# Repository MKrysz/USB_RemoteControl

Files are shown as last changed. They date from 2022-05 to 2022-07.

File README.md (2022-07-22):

# USB Remote Control

## About

The goal of this project was to make an USB dongle allowing you to remotely control your PC with your phone with minimal setup. I achieved it by combining microcontroller with USB HID interface and Bluetooth module. Thanks to utilizing standard HID interface the receiver side is plug-and-play. Only setup is needed on smartphones side, i.e. installing the app and connecting to the dongle.

## Hardware

Schematic

Schematic was made in KiCad

I used STM32F103C6 MCU as it was the cheapest MCU with USB that I had. For Bluettoth connection I used JDY-33 Bluetooth module that can be easily controlled via UART interface. I also added some LEDs and buttons for showing information like state of connection.

The boards were manufactured by JLCPCB

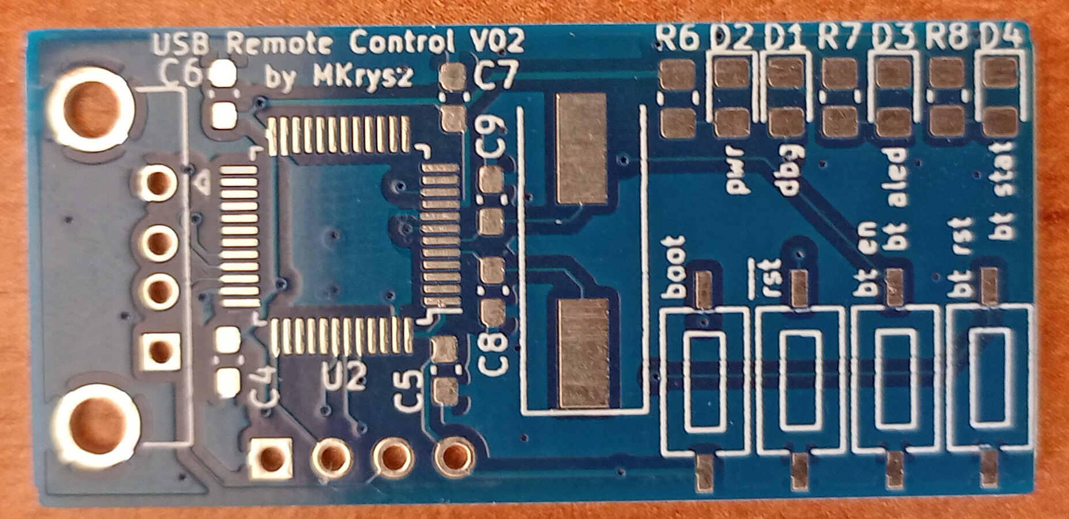
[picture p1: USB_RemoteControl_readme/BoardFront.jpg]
BoardFront

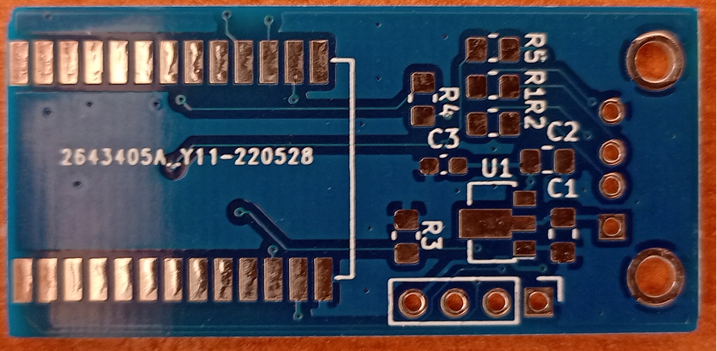
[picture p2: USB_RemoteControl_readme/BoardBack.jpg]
BoardBack


After soldering everything and trying to test the board I found out I could get it to connect to PC via USB. After some research I found out that my MCU is one of few from STM32 family that does not embed pullup resistor on D+ line, so I had to add it. Fully assembled device is shown below:

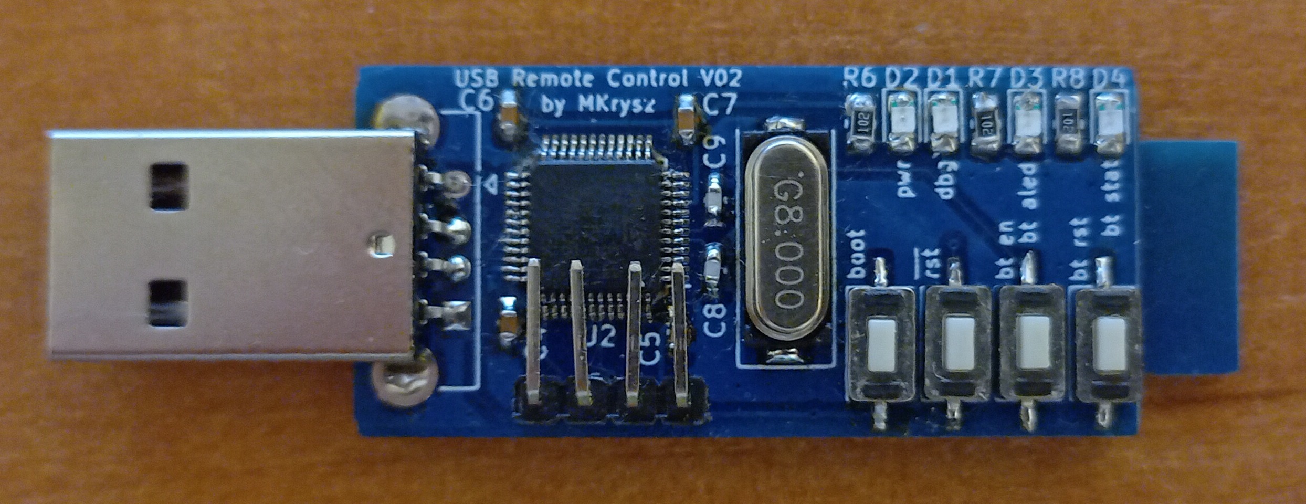
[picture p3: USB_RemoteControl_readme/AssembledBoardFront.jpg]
BoardFront

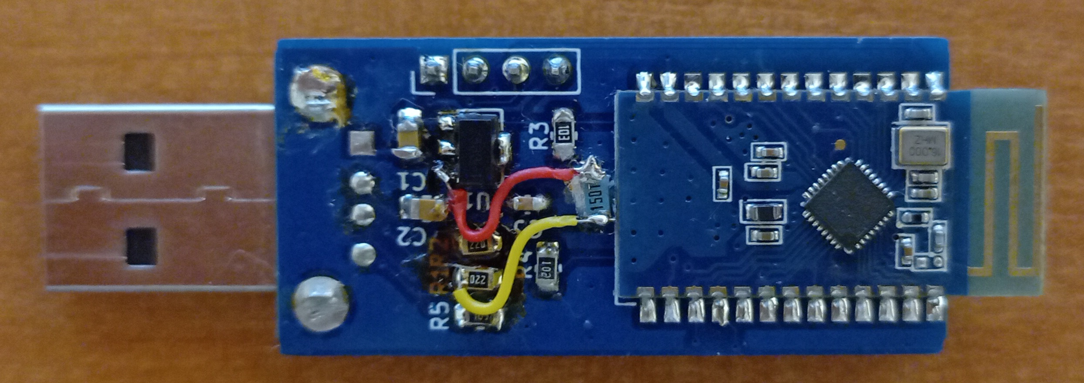
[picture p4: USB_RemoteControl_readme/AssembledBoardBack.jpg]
BoardBack


<!-- ## Embedded Software

Embedded software was made using [STM32CubeMX](https://www.st.com/en/development-tools/stm32cubemx.html) and VSCode using [stm32-for-vscode](https://github.com/bmd-studio/stm32-for-vscode) extension.

F
**Think about what to write here (maybe smth about USB descriptor?)** -->

## Android App

Android App was made using [MIT App Inventor](https://appinventor.mit.edu/), and in design it tries to imitate classical remote control with some additional functions like send text or change current tab in a browser. Current version heavily supports controlling YTMusic web player.

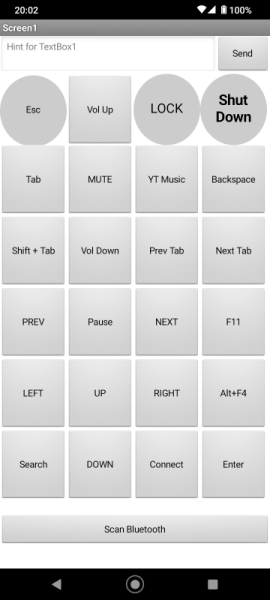
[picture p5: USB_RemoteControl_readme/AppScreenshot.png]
App Screenshot


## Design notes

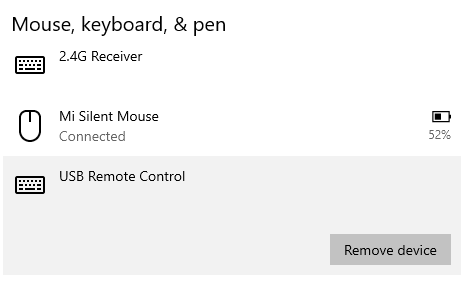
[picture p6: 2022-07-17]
USB_RemoteControl_readme/WindowsSettings.jpg

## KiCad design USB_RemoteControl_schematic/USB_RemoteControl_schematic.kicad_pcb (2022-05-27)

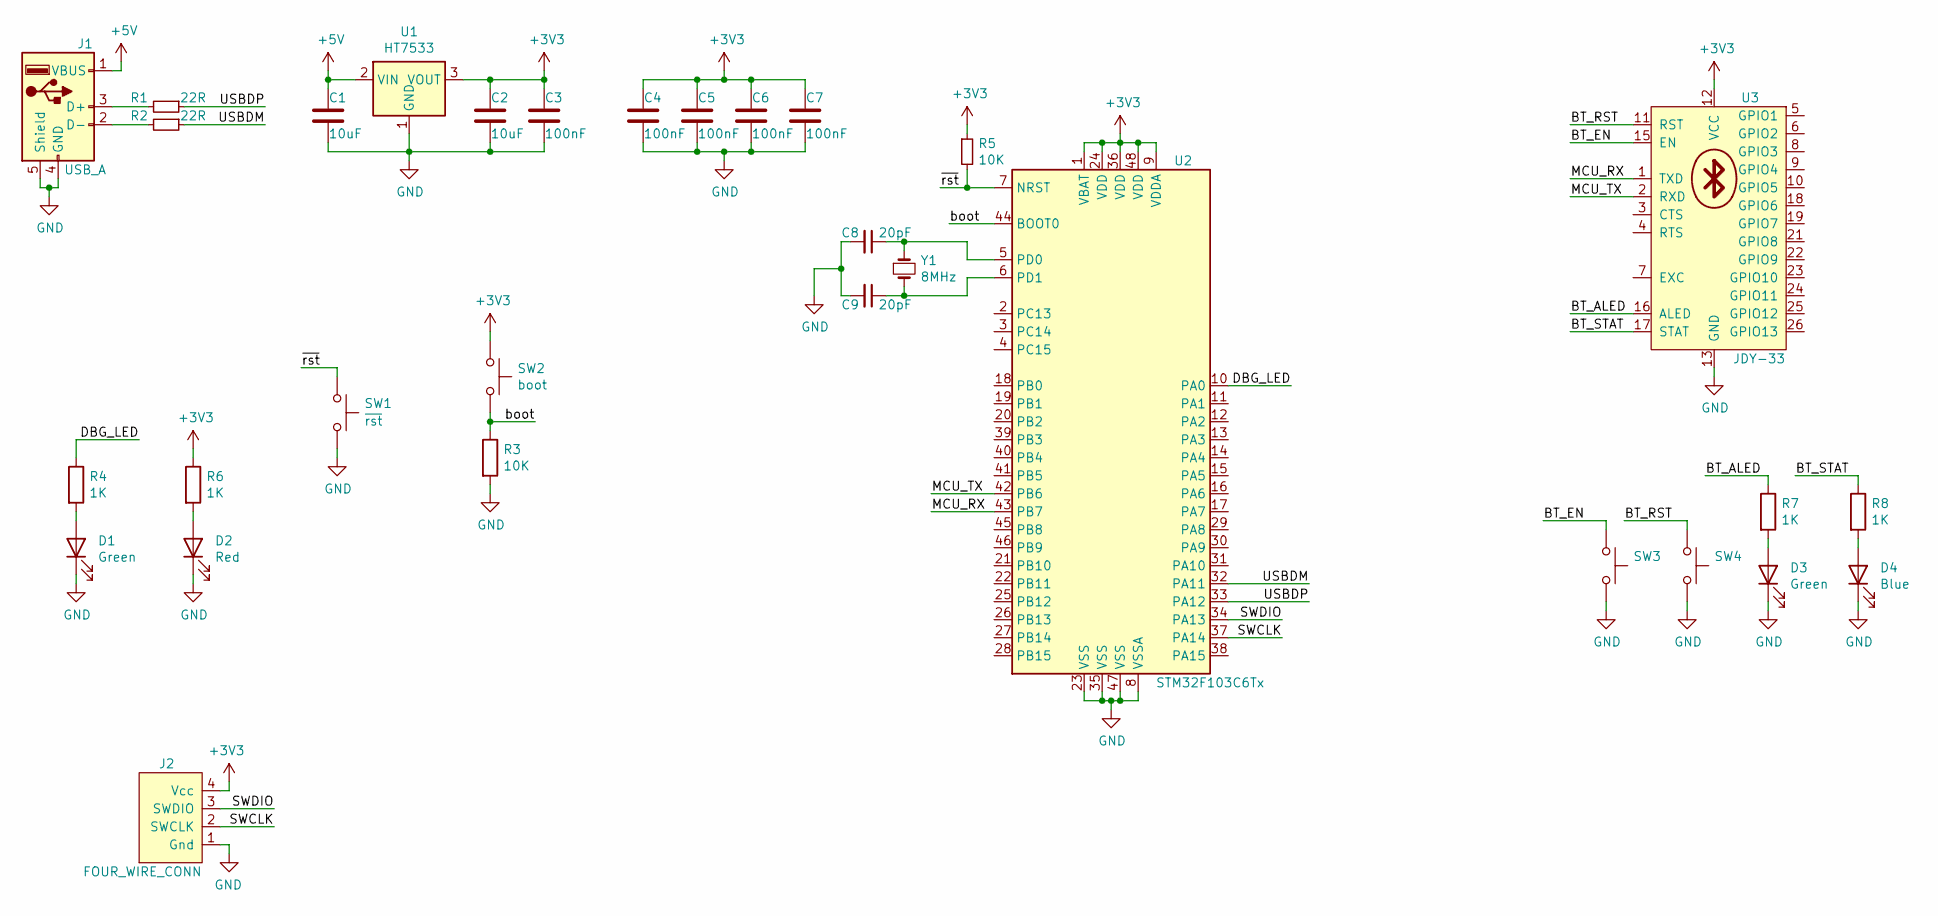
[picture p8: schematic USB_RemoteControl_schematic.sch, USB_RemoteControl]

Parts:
C1, C2: 10uF; C_0805_2012Metric_Pad1.18x1.45mm_HandSolder
C3, C4, C5, C6, C7: 100nF; C_0603_1608Metric_Pad1.08x0.95mm_HandSolder
C8, C9: 20pF; C_0603_1608Metric_Pad1.08x0.95mm_HandSolder
D1, D3: Green; LED_0805_2012Metric_Pad1.15x1.40mm_HandSolder
D2: Red; LED_0805_2012Metric_Pad1.15x1.40mm_HandSolder
D4: Blue; LED_0805_2012Metric_Pad1.15x1.40mm_HandSolder
J1: USB_A; USB_A_Male
J2: FOUR_WIRE_CONN; PinHeader_1x04_P2.54mm_Vertical
R1, R2: 22R; R_0805_2012Metric_Pad1.20x1.40mm_HandSolder
R3, R5: 10K; R_0805_2012Metric_Pad1.20x1.40mm_HandSolder
R4, R6, R7, R8: 1K; R_0805_2012Metric_Pad1.20x1.40mm_HandSolder
SW1: ~rst; TSB008
SW2: boot; TSB008
SW3, SW4: TSB008
U1: HT7533; SOT-89-3
U2: STM32F103C6Tx; LQFP-48_7x7mm_P0.5mm
U3: JDY-33; JDY-33, JDY-32, JDY-31, JDY-30, JDY-09
Y1: 8MHz; Crystal_SMD_HC49-SD

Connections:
+3V3: C2.1, C3.1, C4.1, C5.1, C6.1, C7.1, J2.4 (Vcc), R5.1, R6.1, SW2.1, U1.3 (VOUT), U2.1 (VBAT), U2.9 (VDDA), U2.24 (VDD), U2.36 (VDD), U2.48 (VDD), U3.12 (VCC)
+5V: C1.1, J1.1 (VBUS), U1.2 (VIN)
/BT_ALED: R7.1, U3.16 (ALED)
/BT_EN: SW3.1, U3.15 (EN)
/BT_RST: SW4.1, U3.11 (RST)
/BT_STAT: R8.1, U3.17 (STAT)
/DBG_LED: R4.1, U2.10 (PA0)
/MCU_RX: U2.43 (PB7), U3.1 (TXD)
/MCU_TX: U2.42 (PB6), U3.2 (RXD)
/SWCLK: J2.2 (SWCLK), U2.37 (PA14)
/SWDIO: J2.3 (SWDIO), U2.34 (PA13)
/USBDM: R2.1, U2.32 (PA11)
/USBDP: R1.1, U2.33 (PA12)
/boot: R3.1, SW2.2, U2.44 (BOOT0)
/~rst: R5.2, SW1.1, U2.7 (NRST)
GND: C1.2, C2.2, C3.2, C4.2, C5.2, C6.2, C7.2, C8.2, C9.2, D1.1 (K), D2.1 (K), D3.1 (K), D4.1 (K), J1.4 (GND), J1.5 (Shield), J2.1 (Gnd), R3.2, SW1.2, SW3.2, SW4.2, U1.1 (GND), U2.8 (VSSA), U2.23 (VSS), U2.35 (VSS), U2.47 (VSS), U3.13 (GND)
unnamed: C8.1, U2.5 (PD0), Y1.1
unnamed: C9.1, U2.6 (PD1), Y1.2
unnamed: D1.2 (A), R4.2
unnamed: D2.2 (A), R6.2
unnamed: D3.2 (A), R7.2
unnamed: D4.2 (A), R8.2
unnamed: J1.2 (D-), R2.2
unnamed: J1.3 (D+), R1.2

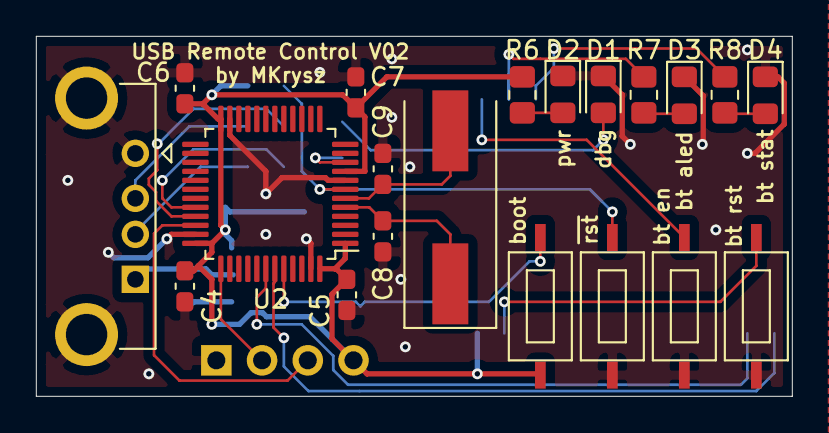
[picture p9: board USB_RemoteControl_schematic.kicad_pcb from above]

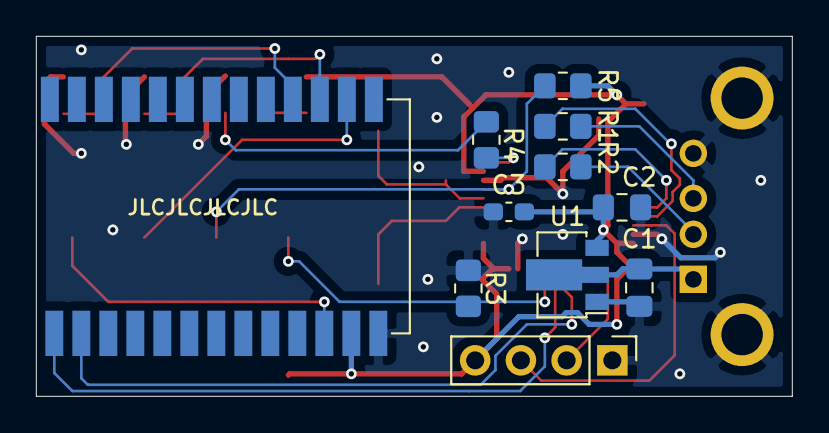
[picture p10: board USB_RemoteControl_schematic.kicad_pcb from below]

Board: 2 copper layers, 42.0 x 20.0 mm, 31 parts (11 on the bottom side), 24 nets.

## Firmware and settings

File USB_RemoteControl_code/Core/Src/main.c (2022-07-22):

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
/* Includes ------------------------------------------------------------------*/
#include "main.h"
#include "usart.h"
#include "usb_device.h"
#include "gpio.h"

/* USER CODE BEGIN Includes */
#include <string.h>
#include "keyboard.h"
/* USER CODE END Includes */

/* USER CODE BEGIN PD */

#define UART_BUFFER_SIZE 128
/* USER CODE END PD */


void SystemClock_Config(void);
/**
  * @brief  The application entry point.
  * @retval int
  */
int main(void)
{
  /* MCU Configuration--------------------------------------------------------*/

  /* Reset of all peripherals, Initializes the Flash interface and the Systick. */
  HAL_Init();

  /* Configure the system clock */
  SystemClock_Config();

  /* Initialize all configured peripherals */
  MX_GPIO_Init();
  MX_USB_DEVICE_Init();
  MX_USART1_UART_Init();
  /* USER CODE BEGIN 2 */
  KEYBOARD_Init();
  char UART_Buffer[UART_BUFFER_SIZE] = "";

  /* USER CODE END 2 */

  /* Infinite loop */
  /* USER CODE BEGIN WHILE */
  while (1)
  {
    for (size_t i = 0; i < UART_BUFFER_SIZE; i++)
    {
      UART_Buffer[i] = 0;
    }
    HAL_UART_Receive(&huart1, UART_Buffer, UART_BUFFER_SIZE, 100);
    if(UART_Buffer[0] == 0)
      continue;
    #define cmdEq(X) (strcmp(UART_Buffer, (X)) == 0)

    if(UART_Buffer[0] == '%'){
      KEYBOARD_Print(&(UART_Buffer[1]), KEYBOARD_MOD_NO_MOD);
    }
    else if(cmdEq("Next")){
       KEYBOARD_MEDIA_Send(KEYBOARD_MEDIA_SCAN_NEXT);
    }
    else if(cmdEq("Prev")){
      KEYBOARD_MEDIA_Send(KEYBOARD_MEDIA_SCAN_PREV);
    }
    else if(cmdEq("Pause")){
      KEYBOARD_MEDIA_Send(KEYBOARD_MEDIA_PAUSE);
    }
    else if(cmdEq("VolUp")){
      KEYBOARD_MEDIA_Send(KEYBOARD_MEDIA_VOL_INC);
    }
    else if(cmdEq("VolDown")){
      KEYBOARD_MEDIA_Send(KEYBOARD_MEDIA_VOL_DEC);
    }
    else if(cmdEq("Mute")){
      KEYBOARD_MEDIA_Send(KEYBOARD_MEDIA_MUTE);
    }
    else if(cmdEq("Esc")){
      KEYBOARD_SendKey(KEYBOARD_KEY_ESCAPE, KEYBOARD_MOD_NO_MOD);
    }
    else if(cmdEq("Lock")){
      KEYBOARD_SendKey(KEYBOARD_KEY_L, KEYBOARD_MOD_LEFT_WIN);
    }
    else if(cmdEq("Left")){
      KEYBOARD_SendKey(KEYBOARD_KEY_LEFT_ARROW, KEYBOARD_MOD_NO_MOD);
    }
    else if(cmdEq("Up")){
      KEYBOARD_SendKey(KEYBOARD_KEY_UP_ARROW, KEYBOARD_MOD_NO_MOD);
    }
    else if(cmdEq("Right")){
      KEYBOARD_SendKey(KEYBOARD_KEY_RIGHT_ARROW, KEYBOARD_MOD_NO_MOD);
    }
    else if(cmdEq("Left")){
      KEYBOARD_SendKey(KEYBOARD_KEY_LEFT_ARROW, KEYBOARD_MOD_NO_MOD);
    }
    else if(cmdEq("Down")){
      KEYBOARD_SendKey(KEYBOARD_KEY_DOWN_ARROW, KEYBOARD_MOD_NO_MOD);
    }
    else if(cmdEq("Reload")){
      KEYBOARD_SendKey(KEYBOARD_KEY_F5, KEYBOARD_MOD_NO_MOD);
    }
    else if(cmdEq("Enter")){
      KEYBOARD_SendKey(KEYBOARD_KEY_ENTER, KEYBOARD_MOD_NO_MOD);
    }
    else if(cmdEq("Tab")){
      KEYBOARD_SendKey(KEYBOARD_KEY_TAB, KEYBOARD_MOD_NO_MOD);
    }
    else if(cmdEq("Search")){
      KEYBOARD_SendKey(KEYBOARD_KEY_SLASH, KEYBOARD_MOD_NO_MOD);
    }
    else if(cmdEq("Backspace")){
      KEYBOARD_SendKey(KEYBOARD_KEY_DELETE, KEYBOARD_MOD_NO_MOD);
    }
    else if(cmdEq("ShutDown")){
      KEYBOARD_SendKey(KEYBOARD_KEY_D, KEYBOARD_MOD_LEFT_WIN);
      HAL_Delay(500);
      KEYBOARD_SendKey(KEYBOARD_KEY_F4, KEYBOARD_MOD_LEFT_ALT);
      HAL_Delay(500);
      KEYBOARD_Enter();
    }
    else if(cmdEq("YTMusic")){
      KEYBOARD_SendKey(KEYBOARD_KEY_X, KEYBOARD_MOD_LEFT_WIN);
      HAL_Delay(500);
      KEYBOARD_SendKey(KEYBOARD_KEY_I, KEYBOARD_MOD_NO_MOD);
      HAL_Delay(500);
      KEYBOARD_Print("start chrome https://music.youtube.com/", KEYBOARD_MOD_NO_MOD);
      KEYBOARD_Enter();
    }
    else if(cmdEq("Search")){
      KEYBOARD_SendKey(KEYBOARD_KEY_SLASH, KEYBOARD_MOD_NO_MOD);
    }
    else if(cmdEq("PrevTab")){
      KEYBOARD_SendKey(KEYBOARD_KEY_TAB, (KEYBOARD_MOD_LEFT_CTRL | KEYBOARD_MOD_RIGHT_SHIFT));
    }
    else if(cmdEq("NextTab")){
      KEYBOARD_SendKey(KEYBOARD_KEY_TAB, KEYBOARD_MOD_LEFT_CTRL);
    }
    else if(cmdEq("Connect")){
      KEYBOARD_SendKey(KEYBOARD_KEY_K, KEYBOARD_MOD_LEFT_WIN);
    }
    else if(cmdEq("F11")){
      KEYBOARD_SendKey(KEYBOARD_KEY_F11, KEYBOARD_MOD_NO_MOD);
    }
    else if(cmdEq("AltF4")){
      KEYBOARD_SendKey(KEYBOARD_KEY_F4, KEYBOARD_MOD_LEFT_ALT);
    }
    // else{
    //   KEYBOARD_Print("NOOP\n", KEYBOARD_MOD_NO_MOD);
    //   KEYBOARD_Print(UART_Buffer, KEYBOARD_MOD_NO_MOD);
    // }

    /* USER CODE END WHILE */

    /* USER CODE BEGIN 3 */    // Send HID report
  }
  /* USER CODE END 3 */
}

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


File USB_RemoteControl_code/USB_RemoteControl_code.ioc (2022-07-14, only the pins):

Mcu.UserName=STM32F103C6Tx
PA0-WKUP.GPIO_Label=DBG_LED
PA0-WKUP.Signal=GPIO_Output
PA11.Signal=USB_DM
PA12.Signal=USB_DP
PA13.Signal=SYS_JTMS-SWDIO
PA14.Signal=SYS_JTCK-SWCLK
PB6.Signal=USART1_TX
PB7.Signal=USART1_RX
PD0-OSC_IN.Signal=RCC_OSC_IN
PD1-OSC_OUT.Signal=RCC_OSC_OUT

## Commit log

2022-05-25 Upload Version01
    [LaserAutoSkipper_RX_schematic-B_Cu.gbl, LaserAutoSkipper_RX_schematic-B_Mask.gbs, LaserAutoSkipper_RX_schematic-B_Paste.gbp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]
2022-05-25 Completed schematic for Version02
    [USB_RemoteControl_schematic.kicad_pcb, USB_RemoteControl_schematic.sch]
2022-05-25 Finished PCB
    [USB_RemoteControl_schematic.kicad_pcb, USB_RemoteControl_schematic.sch]
2022-05-26 Added signature
    [USB_RemoteControl_schematic.kicad_pcb]
2022-05-27 Generated new PCB's gerbers
    [LaserAutoSkipper_RX_schematic-B_Cu.gbl, LaserAutoSkipper_RX_schematic-B_Mask.gbs, LaserAutoSkipper_RX_schematic-B_Paste.gbp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]
2022-05-29 Improved readability of the schematic
    [USB_RemoteControl_schematic.sch]
2022-07-17 Added More buttons and icon to the app
2022-07-22 Fixed prevTab functionality not working
    [main.c]

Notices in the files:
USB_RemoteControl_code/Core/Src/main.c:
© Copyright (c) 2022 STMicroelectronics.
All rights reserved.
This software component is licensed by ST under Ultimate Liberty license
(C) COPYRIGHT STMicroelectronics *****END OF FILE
